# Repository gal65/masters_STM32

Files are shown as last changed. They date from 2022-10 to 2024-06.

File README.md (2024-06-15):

# STM32 board and shield

STM32-based board with shield. Features 12V supply, and voltage converters to power HerkuleX servos as well as the MCU itself. 

Features I2C header (connects to rotary encoder), connection to HerkuleX servo, USB, IMU and temperature sensor, GPIO breakout and CAN bus. Programmable over SWD.

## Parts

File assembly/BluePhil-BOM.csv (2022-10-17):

Designator | Quantity | Value | Footprint | LCSC Part #
C102 C200 C300 C402 C500 | 5 | 10u | Capacitor_SMD:C_0603_1608Metric | C19702
C101 C201 C202 C203 C204 C205 C206 C212 C301 C302 C400 C401 C403 C404 C405 C501 C502 C503 C504 | 19 | 100n | Capacitor_SMD:C_0402_1005Metric | C1525
C100 C207 C208 | 3 | 2u2 | Capacitor_SMD:C_0603_1608Metric | C23630
C209 C210 | 2 | 10p | Capacitor_SMD:C_0402_1005Metric | C32949
C303 | 1 | 10n | Capacitor_SMD:C_0402_1005Metric | C15195
C406 | 1 | 2n2 | Capacitor_SMD:C_0402_1005Metric | C1531
D100 | 1 | LM5Z2V7T1G | Diode_SMD:D_SOD-523 | C131797
D101 | 1 | B5819W | Diode_SMD:D_SOD-123 | C8598
D102 | 1 | GREEN | LED_SMD:LED_0603_1608Metric | C72043
D200 | 1 | BLUE | LED_SMD:LED_0603_1608Metric | C72041
D201 D202 D203 D204 D205 D300 D500 D501 D502 D503 D504 D505 D506 D507 D508 D509 | 16 | RCLAMP0521P-N | Diode_SMD:D_0402_1005Metric | C316043
FB100 FB500 FB501 | 3 | 100R | Inductor_SMD:L_0603_1608Metric | C1002
J200 | 1 | SWD | Connector_PinHeader_1.27mm:PinHeader_2x05_P1.27mm_Vertical | C239059
J201 | 1 | USB_B_Micro | BluePhil-Footprints:MicroXNJ | C404969
J300 | 1 | U.FL | BluePhil-Footprints:BWIPX-1-001E | C496552
J500 | 1 | Micro_SD_Card | BluePhil-Footprints:TF-102-15 | C266609
L1 | 1 | 15u | BluePhil-Footprints:MPIT4018-150M-LF | C281265
L300 | 1 | 100n | Inductor_SMD:L_0402_1005Metric | C22726
Q100 | 1 | AO3401A | Package_TO_SOT_SMD:SOT-23 | C693260
R100 | 1 | 470R | Resistor_SMD:R_0402_1005Metric | C25117
R101 | 1 | 3k4 | Resistor_SMD:R_0402_1005Metric | C4940
R102 | 1 | 1k02 | Resistor_SMD:R_0402_1005Metric | C85373
R200 R202 | 2 | 10k | Resistor_SMD:R_0402_1005Metric | C25744
R201 R301 R302 R500 R501 R502 R503 R504 R505 | 9 | 0R | Resistor_SMD:R_0402_1005Metric | C17168
R203 R204 | 2 | 2k2 | Resistor_SMD:R_0402_1005Metric | C25879
R103 R205 | 2 | 1k | Resistor_SMD:R_0402_1005Metric | C11702
R206 R207 R208 | 3 | 22R | Resistor_SMD:R_0402_1005Metric | C25092
R300 | 1 | 10R | Resistor_SMD:R_0402_1005Metric | C25077
R506 R507 R508 R509 R510 | 5 | 47k | Resistor_SMD:R_0402_1005Metric | C25792
R511 | 1 | 120R | Resistor_SMD:R_0402_1005Metric | C25079
SW200 | 1 | SW_SPDT | Button_Switch_SMD:SW_SPDT_PCM12 | C431541
U100 | 1 | LM2842X | Package_TO_SOT_SMD:TSOT-23-6 | C9403
U200 | 1 | STM32F405RGT6 | Package_QFP:LQFP-64_10x10mm_P0.5mm | C15742
U201 | 1 | USBLC6-2SC6 | Package_TO_SOT_SMD:SOT-23-6 | C7519
U300 | 1 | MAX-M8Q | RF_GPS:ublox_MAX | C90770
U400 | 1 | SPL06-007 | Package_LGA:Bosch_LGA-8_2x2.5mm_P0.65mm_ClockwisePinNumbering | C233787
U401 | 1 | MPU-6050 | Sensor_Motion:InvenSense_QFN-24_4x4mm_P0.5mm | C24112
U500 | 1 | TJA1051T-3 | Package_SO:SOIC-8_3.9x4.9mm_P1.27mm | C38695
Y200 | 1 | 16MHz | Crystal:Crystal_SMD_3225-4Pin_3.2x2.5mm | C13738
 | 1 | BM04B-SURS |  | C495551

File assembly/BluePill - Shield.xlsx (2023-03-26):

Component Count: | 33
Ref | Qnty | Value | Cmp name | Footprint | Vendor | Vendor part number
C202, C209, C502, C503, | 4 | 100n ceramic X5R | C_0402 | SnapEDA Library:CAPC1005X55N | LCSC | C1525
C204, C207, C210, C211, | 4 | 10u ceramic X5R | C_0603 | SnapEDA Library:CAPC1608X90N | LCSC | C19702
D202, D206, | 2 | 30V 2A | D_Schottky | SnapEDA Library:B230A-13-F | Digikey | B230A-FDICT-ND
D501, | 1 | GREEN | LED_Small | LED_SMD:LED_0603_1608Metric | LCSC | C72043
F201, F202, | 2 | 0ZCG0050FF2C | 0ZCG0050FF2C | SnapEDA Library:0ZCG0050FF2C | Digikey | 507-1761-1-ND
IC201, IC202, | 2 | ADP2301AUJZ-R7 | ADP2301AUJZ-R7 | SOT95P280X100-6N | Digikey | 505-ADP2301AUJZ-R7CT-ND
J201, | 1 | AMASS_XT30PW-F | Conn_01x02 | Connector_AMASS:AMASS_XT30PW-F_1x02_P2.50mm_Horizontal | Aliexpress | N/A
J202, | 1 | AMASS_XT30PW-M | Conn_01x02 | Connector_AMASS:AMASS_XT30PW-M_1x02_P2.50mm_Horizontal | Aliexpress | N/A
J501, | 1 | Conn_01x04 | Conn_01x04 | SnapEDA Library:JST_B4B-XH-A(LF)(SN) | Aliexpress | N/A
J502, | 1 | Conn_01x02 | Conn_01x02 | SnapEDA Library:JST_B2B-XH-A(LF)(SN) | Aliexpress | N/A
J504, | 1 | Conn_01x10 | Conn_01x10 | Connector_PinSocket_2.54mm:PinSocket_1x10_P2.54mm_Vertical | Digikey | SAM1198-10-ND
J506, | 1 | Conn_01x13 | Conn_01x13 | Connector_PinSocket_2.54mm:PinSocket_1x13_P2.54mm_Vertical | Digikey | SAM1198-13-ND
L201, L203, | 2 | 4.7u 2.0A | L | SnapEDA Library:CDRH5D28RHPNP-4R7NC | Digikey | 308-2068-1-ND
R201, R205, R212, | 3 | 56k | R_Small | Resistor_SMD:R_0402_1005Metric | Digikey | 311-56.0KLRCT-ND
R202, | 1 | 6.8k | R_Small | Resistor_SMD:R_0402_1005Metric | Digikey | 311-6.80KLRCT-ND
R206, R213, | 2 | 10.2k | R_Small | Resistor_SMD:R_0402_1005Metric | Digikey | YAG2950CT-ND
R210, | 1 | 52.3k | R_Small | Resistor_SMD:R_0402_1005Metric | Digikey | YAG3179CT-ND
R211, | 1 | 10k | R_Small | Resistor_SMD:R_0402_1005Metric | LCSC | C25744
R501, | 1 | 1k | R_Small | Resistor_SMD:R_0402_1005Metric | LCSC | C11702
U502, | 1 | TXS0102DCU | TXS0102DCU | Package_SO:VSSOP-8_2.3x2mm_P0.5mm | Digikey | 296-21931-1-ND

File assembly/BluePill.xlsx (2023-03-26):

Component Count: | 66
Ref | Qnty | Value | Cmp name | Footprint | Vendor | Vendor part number
C201, C205, | 2 | 1u ceramic X7R | C0603C105K3RACTU | SnapEDA Library:C0603C105K3RACTU | Digikey | 399-C0603C105K3RAC7867CT-ND
C301, C302, | 2 | 10p | C_Small | Capacitor_SMD:C_0402_1005Metric | LCSC | C32949
C303, | 1 | 10u | C_Small | Capacitor_SMD:C_0603_1608Metric | Digikey | 1276-1119-1-ND
C304, C306, | 2 | 2u2 | C_Small | Capacitor_SMD:C_0603_1608Metric | LCSC | C23630
C305, C307, C308, C309, C310, C311, C312, C402 C501, | 9 | 100n X7R | C_Small | Capacitor_SMD:C_0402_1005Metric | LCSC | C1525
C401, | 1 | 10n | C_Small | Capacitor_SMD:C_0402_1005Metric | LCSC | C15195
C403, | 1 | 2u2 X7R | C_Small | Capacitor_SMD:C_0402_1005Metric | Digikey | 490-GRM155Z71A225KE44DCT-ND
D204, | 1 | GREEN | LED_Small | LED_SMD:LED_0603_1608Metric | LCSC | C72043
D301, | 1 | BLUE | LED_Small | LED_SMD:LED_0603_1608Metric | LCSC | C72041
D302, D303, D304, D305, D306, D502, D503, | 7 | RCLAMP0521P-N | D_TVS | Diode_SMD:D_0402_1005Metric | LCSC | C316043
D307, | 1 | YELLOW | LED_Small | LED_SMD:LED_0603_1608Metric | Digikey | 160-1831-1-ND
D308, | 1 | RED | LED_Small | LED_SMD:LED_0603_1608Metric | Digikey | 160-1830-1-ND
H501, H502, | 2 | MountingHole_Pad | MountingHole_Pad | MountingHole:MountingHole_3.2mm_M3_Pad_Via | N/A | N/A
J301, | 1 | SWD | Conn_02x05_Odd_Even | Connector_PinHeader_1.27mm:PinHeader_2x05_P1.27mm_Vertical | LCSC | C239059
J302, | 1 | USB4110-GF-A_REVB | USB4110-GF-A_REVB | SnapEDA Library:GCT_USB4110-GF-A_REVB | Digikey | 2073-USB4110-GF-A-1-ND
J401, | 1 | BM04B-SURS-TFLFSN | BM04B-SURS-TFLFSN | SnapEDA Library:JST_BM04B-SURS-TF(LF)(SN) | LCSC | C495551
J503, | 1 | Conn_01x10 | Conn_01x10 | Connector_PinSocket_2.54mm:PinSocket_1x10_P2.54mm_Vertical | Digikey | S7043-ND
J505, | 1 | Conn_01x13 | Conn_01x13 | Connector_PinSocket_2.54mm:PinSocket_1x13_P2.54mm_Vertical | Digikey | S7046-ND
JP401, JP402, | 2 | SolderJumper_3_Bridged12 | SolderJumper_3_Bridged12 | Jumper:SolderJumper-3_P1.3mm_Bridged12_Pad1.0x1.5mm | N/A | N/A
R208, R306, R313, R317, | 4 | 1k | R_Small | Resistor_SMD:R_0402_1005Metric | LCSC | C11702
R301, R307, R309, R310, R311, R312, | 6 | 2k2 | R_Small | Resistor_SMD:R_0402_1005Metric | LCSC | C25879
R302, R401, R402, | 3 | 0R | R_Small | Resistor_SMD:R_0402_1005Metric | LCSC | C17168
R303, R308, | 2 | 10k | R_Small | Resistor_SMD:R_0402_1005Metric | LCSC | C25744
R304, R305, | 2 | 5k1 | R_Small | Resistor_SMD:R_0402_1005Metric | Digikey | 311-5.10KLRCT-ND
R314, R315, R316, | 3 | 22R | R_Small | Resistor_SMD:R_0402_1005Metric | LCSC | C25092
R502, | 1 | 120R | R_Small | Resistor_SMD:R_0402_1005Metric | LCSC | C25079
SW301, | 1 | SW_SPDT | SW_SPDT | Button_Switch_SMD:SW_SPDT_PCM12 | Digikey | 401-2016-1-ND
U201, | 1 | LP5907QMFX-3.3Q1 | LP5907QMFX-3.3Q1 | SnapEDA Library:SOT95P280X145-5N | Digikey | 296-40365-1-ND
U301, | 1 | STM32F405RGT6 | STM32F405RGTx | Package_QFP:LQFP-64_10x10mm_P0.5mm | LCSC | C15742
U302, | 1 | USBLC6-2SC6 | USBLC6-2SC6 | Package_TO_SOT_SMD:SOT-23-6 | LCSC | C7519
U401, | 1 | ICM-42670-P | ICM-42670-P | SnapEDA Library:IC_ICM-42670-P | Digikey | 1428-ICM-42670-PCT-ND
U501, | 1 | SN65HVD232QDRQ1 | SN65HVD232QDRQ1 | SnapEDA Library:SOIC127P599X175-8N | Digikey | 296-15381-1-ND
Y301, | 1 | 16MHz | Crystal_GND24_Small | Crystal:Crystal_SMD_3225-4Pin_3.2x2.5mm | LCSC | C13738

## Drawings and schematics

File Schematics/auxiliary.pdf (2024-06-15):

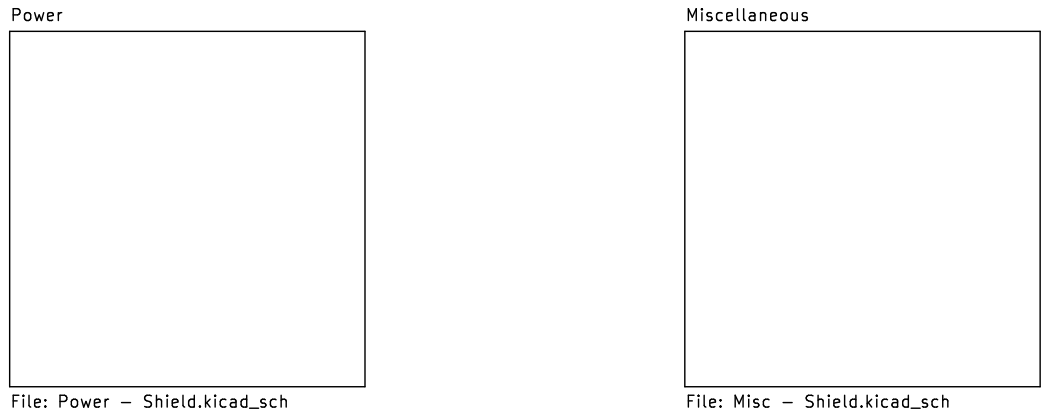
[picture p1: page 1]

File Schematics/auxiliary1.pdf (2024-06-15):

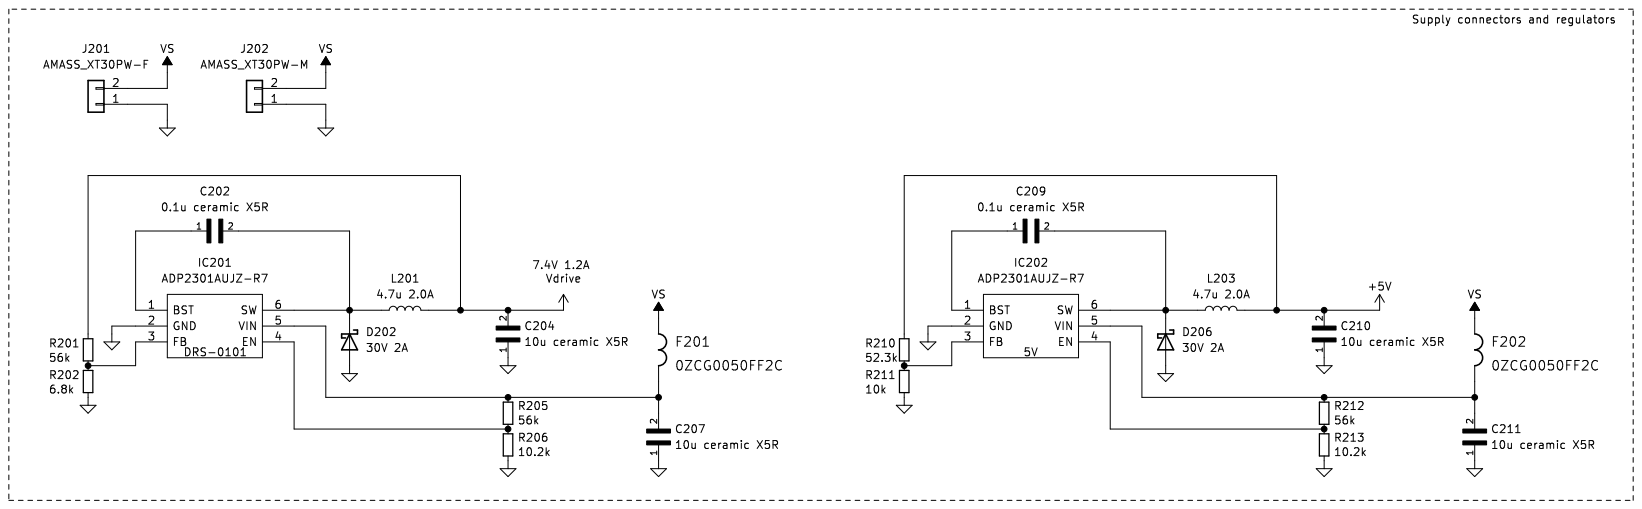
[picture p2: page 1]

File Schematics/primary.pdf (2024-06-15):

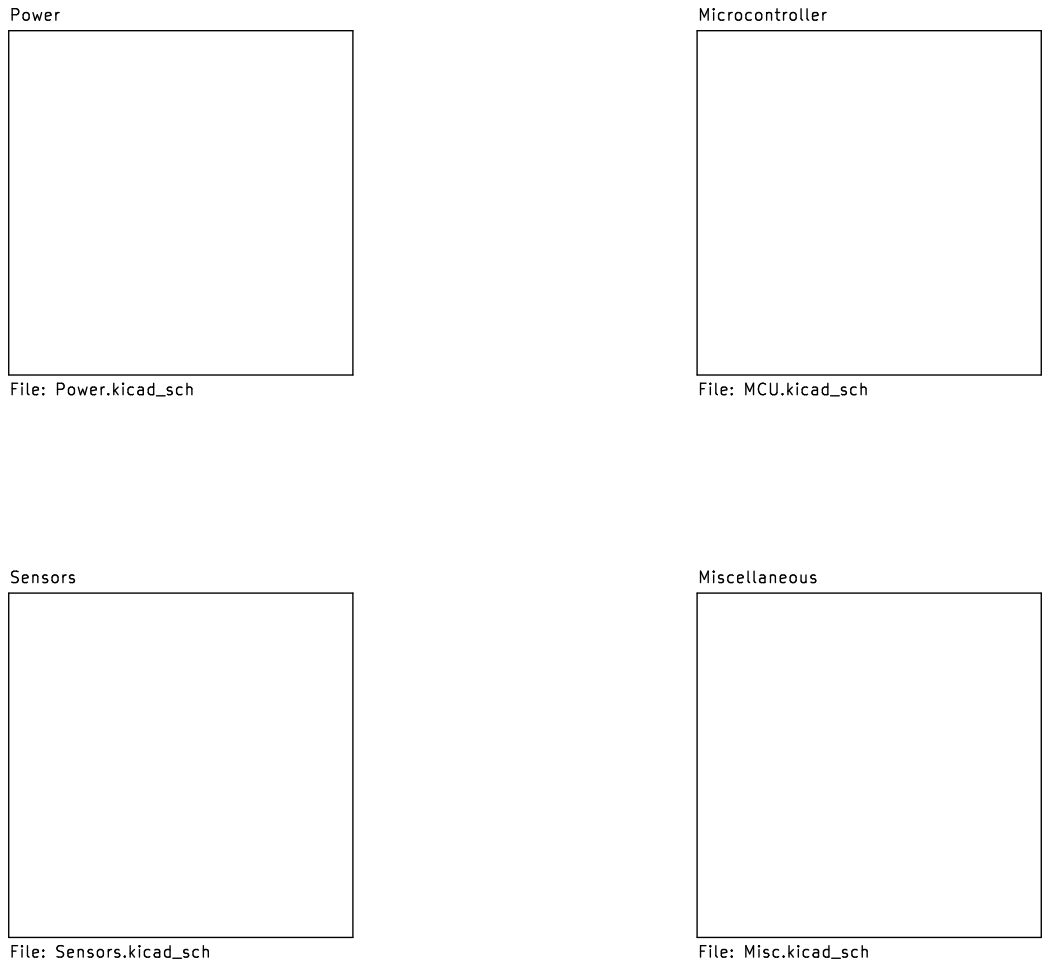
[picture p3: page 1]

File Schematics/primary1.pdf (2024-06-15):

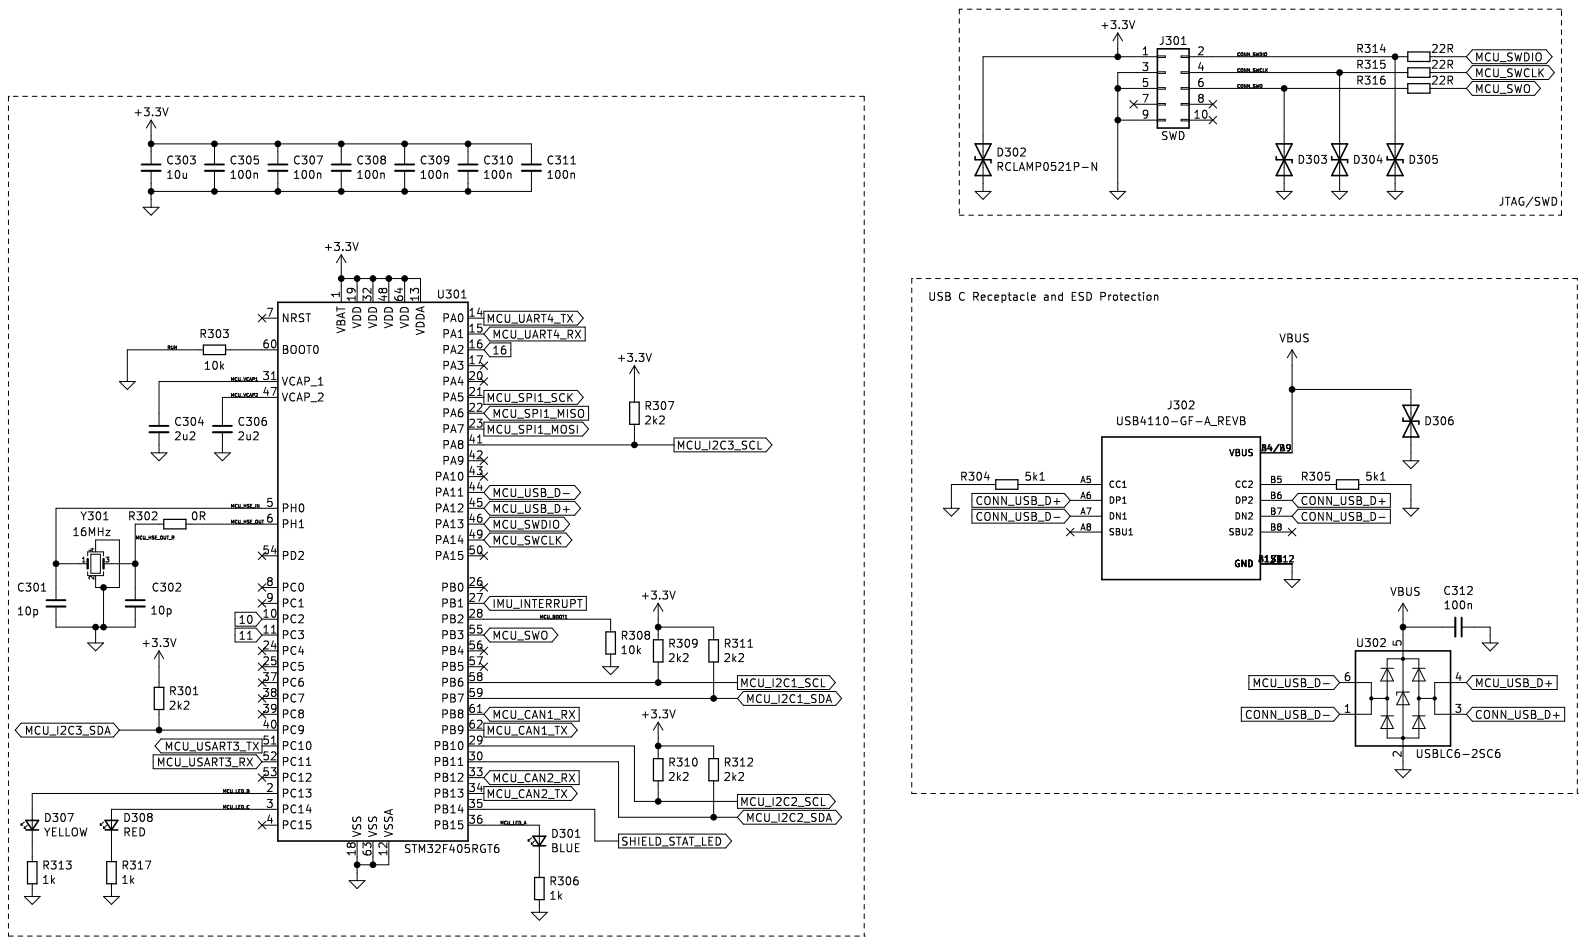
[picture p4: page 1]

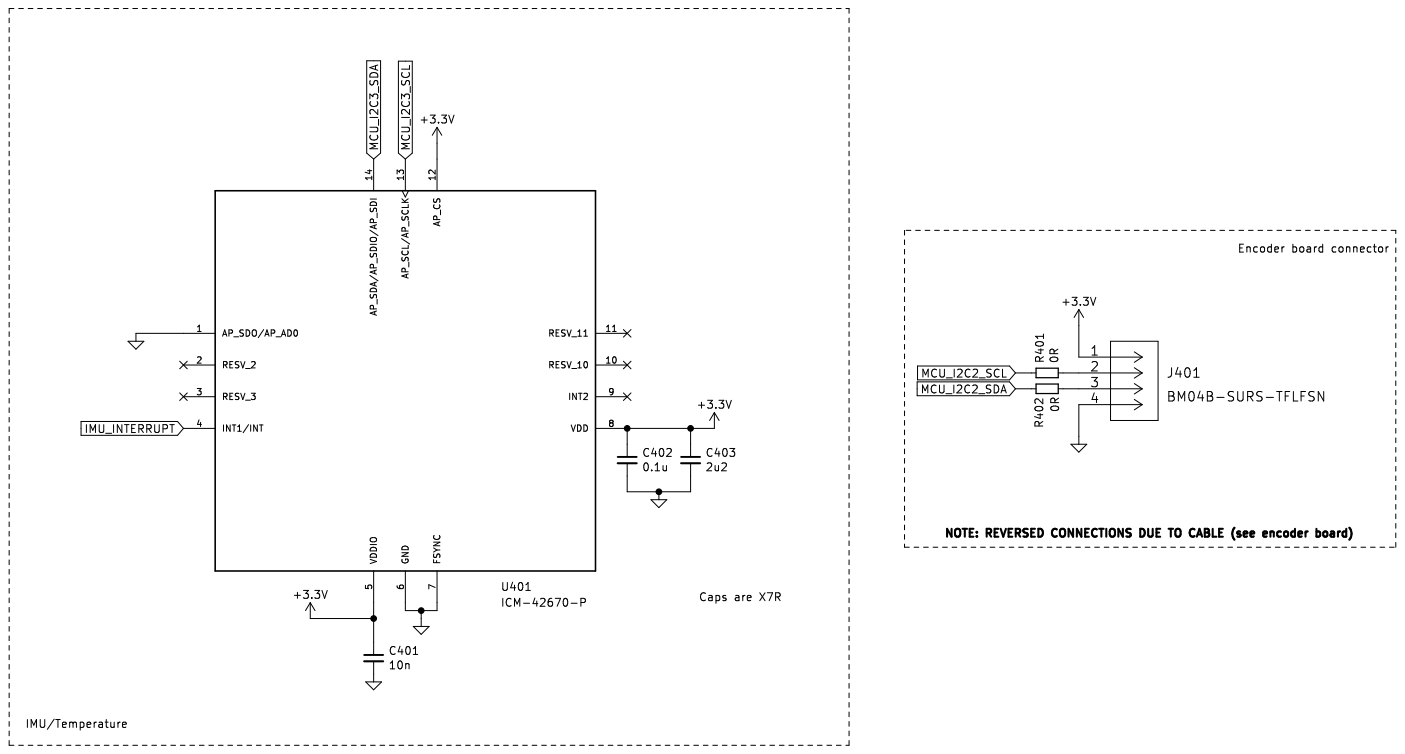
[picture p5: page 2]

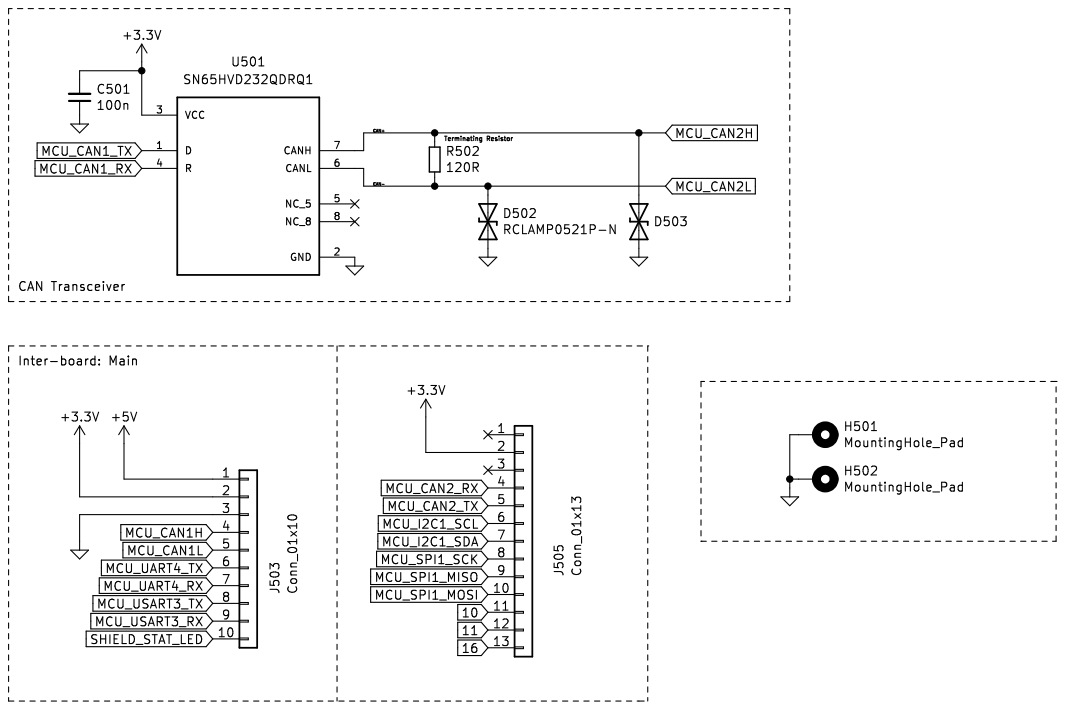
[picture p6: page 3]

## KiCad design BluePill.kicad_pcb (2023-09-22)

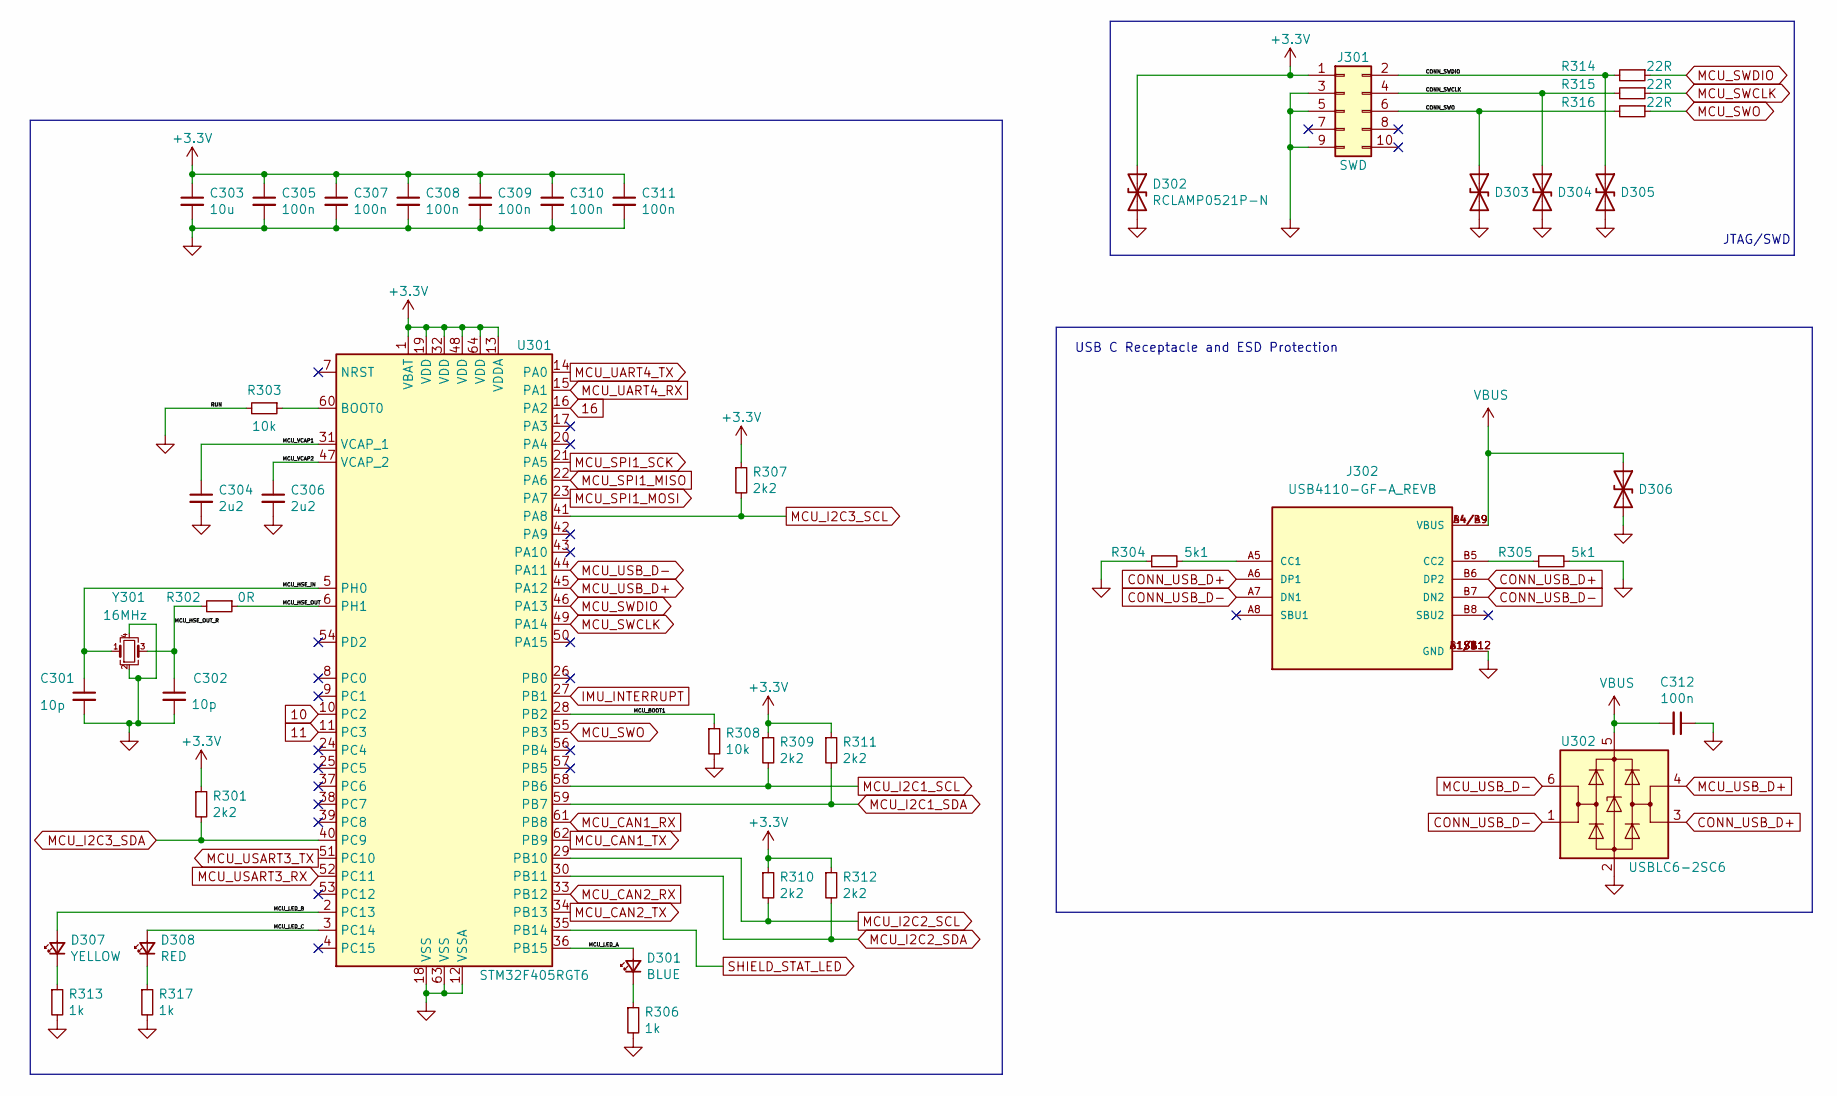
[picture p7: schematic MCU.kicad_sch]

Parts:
C301, C302: 10p; C_0402_1005Metric; LCSC Part # C32949
C303: 10u; C_0603_1608Metric; LCSC Part # C19702
C304, C306: 2u2; C_0603_1608Metric; LCSC Part # C23630
C305, C307, C308, C309, C310, C311, C312: 100n; C_0402_1005Metric; LCSC Part # C1525
D301: BLUE; LED_0603_1608Metric; LCSC Part # C72041
D302, D303, D304, D305, D306: RCLAMP0521P-N; D_0402_1005Metric; LCSC Part # C316043
D307: YELLOW; LED_0603_1608Metric; LCSC Part # C72041
D308: RED; LED_0603_1608Metric; LCSC Part # C72041
J301: SWD; PinHeader_2x05_P1.27mm_Vertical; LCSC Part # C239059
J302: USB4110-GF-A_REVB; GCT_USB4110-GF-A_REVB; PARTREV B
R301, R307, R309, R310, R311, R312: 2k2; R_0402_1005Metric; LCSC Part # C25879
R302: 0R; R_0402_1005Metric; LCSC Part # C17168
R303, R308: 10k; R_0402_1005Metric; LCSC Part # C25744
R304, R305: 5k1; R_0402_1005Metric; LCSC Part # C25879
R306, R313, R317: 1k; R_0402_1005Metric; LCSC Part # C11702
R314, R315, R316: 22R; R_0402_1005Metric; LCSC Part # C25092
U301: STM32F405RGT6; LQFP-64_10x10mm_P0.5mm; LCSC Part # C15742
U302: USBLC6-2SC6; SOT-23-6; LCSC Part # C7519
Y301: 16MHz; Crystal_SMD_3225-4Pin_3.2x2.5mm; LCSC Part # C13738

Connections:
10: U301.10 (PC2); also elsewhere on the board
11: U301.11 (PC3); also elsewhere on the board
16: U301.16 (PA2); also elsewhere on the board
+3V3: C303.1, C305.1, C307.1, C308.1, C309.1, C310.1, C311.1, D302.1 (A1), J301.1, R301.1, R307.1, R309.1, R310.1, R311.1, R312.1, U301.1 (VBAT), U301.13 (VDDA), U301.19 (VDD), U301.32 (VDD), U301.48 (VDD), U301.64 (VDD); also elsewhere on the board
/Microcontroller/CONN_SWCLK: D304.1 (A1), J301.4, R315.2
/Microcontroller/CONN_SWDIO: D305.1 (A1), J301.2, R314.2
/Microcontroller/CONN_SWO: D303.1 (A1), J301.6, R316.2
/Microcontroller/MCU_BOOT1: R308.1, U301.28 (PB2)
/Microcontroller/MCU_HSE_IN: C301.1, U301.5 (PH0), Y301.1
/Microcontroller/MCU_HSE_OUT: R302.1, U301.6 (PH1)
/Microcontroller/MCU_HSE_OUT_R: C302.1, R302.2, Y301.3
/Microcontroller/MCU_LED_A: D301.2 (A), U301.36 (PB15)
/Microcontroller/MCU_LED_B: D307.2 (A), U301.2 (PC13)
/Microcontroller/MCU_LED_C: D308.2 (A), U301.3 (PC14)
/Microcontroller/MCU_VCAP1: C304.1, U301.31 (VCAP_1)
/Microcontroller/MCU_VCAP2: C306.1, U301.47 (VCAP_2)
CONN_USB_D+: J302.A6 (DP1), J302.B6 (DP2), U302.3 (I/O2)
CONN_USB_D-: J302.A7 (DN1), J302.B7 (DN2), U302.1 (I/O1)
GND: C301.2, C302.2, C303.2, C304.2, C305.2, C306.2, C307.2, C308.2, C309.2, C310.2, C311.2, C312.1, D302.2 (A2), D303.2 (A2), D304.2 (A2), D305.2 (A2), D306.2 (A2), J301.3, J301.5, J301.9, J302.A1/B12 (GND), J302.B1/A12 (GND), J302.S1 (GND), J302.S2 (GND), J302.S3 (GND), J302.S4 (GND), R303.2, R304.1, R305.2, R306.2, R308.2, R313.2, R317.2, U301.12 (VSSA), U301.18 (VSS), U301.63 (VSS), U302.2 (GND), Y301.2, Y301.4; also elsewhere on the board
IMU_INTERRUPT: U301.27 (PB1); also elsewhere on the board
MCU_CAN1_RX: U301.61 (PB8); also elsewhere on the board
MCU_CAN1_TX: U301.62 (PB9); also elsewhere on the board
MCU_CAN2_RX: U301.33 (PB12); also elsewhere on the board
MCU_CAN2_TX: U301.34 (PB13); also elsewhere on the board
MCU_I2C1_SCL: R309.2, U301.58 (PB6); also elsewhere on the board
MCU_I2C1_SDA: R311.2, U301.59 (PB7); also elsewhere on the board
MCU_I2C3_SCL: R307.2, U301.41 (PA8); also elsewhere on the board
MCU_I2C3_SDA: R301.2, U301.40 (PC9); also elsewhere on the board
MCU_SPI1_MISO: U301.22 (PA6); also elsewhere on the board
MCU_SPI1_MOSI: U301.23 (PA7); also elsewhere on the board
MCU_SPI1_SCK: U301.21 (PA5); also elsewhere on the board
MCU_SWCLK: R315.1, U301.49 (PA14)
MCU_SWDIO: R314.1, U301.46 (PA13)
MCU_SWO: R316.1, U301.55 (PB3)
MCU_UART4_RX: U301.15 (PA1); also elsewhere on the board
MCU_UART4_TX: U301.14 (PA0); also elsewhere on the board
MCU_USART3_RX: U301.52 (PC11); also elsewhere on the board
MCU_USART3_TX: U301.51 (PC10); also elsewhere on the board
MCU_USB_D+: U301.45 (PA12), U302.4 (I/O2)
MCU_USB_D-: U301.44 (PA11), U302.6 (I/O1)
unnamed: D301.1 (K), R306.1
unnamed: D307.1 (K), R313.1
unnamed: D308.1 (K), R317.1
unnamed: J302.A5 (CC1), R304.2
unnamed: J302.B5 (CC2), R305.1
unnamed: R303.1, U301.60 (BOOT0)
SHIELD_STAT_LED: U301.35 (PB14); also elsewhere on the board
VBUS: C312.2, D306.1 (A1), J302.A4/B9 (VBUS), J302.B4/A9 (VBUS), U302.5 (VBUS)

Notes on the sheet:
USB C Receptacle and ESD Protection
JTAG/SWD

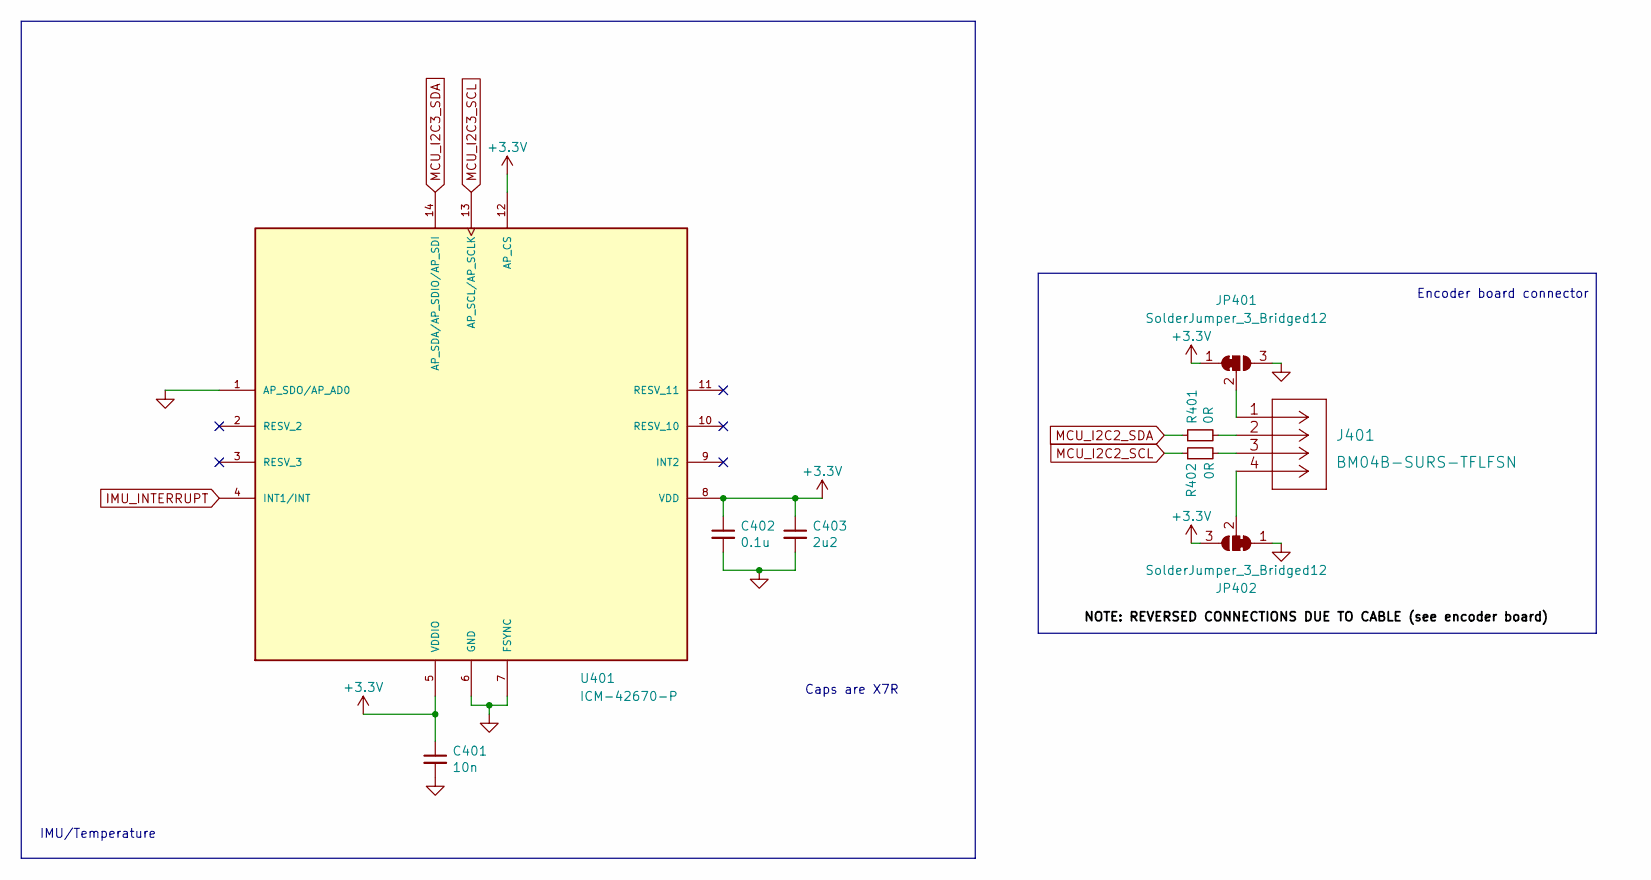
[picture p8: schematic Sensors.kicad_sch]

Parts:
C401: 10n; C_0402_1005Metric; LCSC Part # C1531
C402: 0.1u; C_0402_1005Metric; LCSC Part # C1525
C403: 2u2; C_0402_1005Metric; LCSC Part # C1531
J401: BM04B-SURS-TFLFSN; JST_BM04B-SURS-TF(LF)(SN)
JP401, JP402: SolderJumper_3_Bridged12; SolderJumper-3_P1.3mm_Bridged12_Pad1.0x1.5mm
R401, R402: 0R; R_0402_1005Metric; LCSC Part # C25079
U401: ICM-42670-P; IC_ICM-42670-P; PARTREV 1.0

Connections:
+3V3: C401.1, C402.1, C403.1, J401.1, JP401.1 (A), JP401.2 (C), JP402.3 (B), U401.5 (VDDIO), U401.8 (VDD), U401.12 (AP_CS); also elsewhere on the board
GND: C401.2, C402.2, C403.2, J401.4, JP401.3 (B), JP402.1 (A), JP402.2 (C), U401.1 (AP_SDO/AP_AD0), U401.6 (GND), U401.7 (FSYNC); also elsewhere on the board
IMU_INTERRUPT: U401.4 (INT1/INT); also elsewhere on the board
MCU_I2C3_SCL: U401.13 (AP_SCL/AP_SCLK); also elsewhere on the board
MCU_I2C3_SDA: U401.14 (AP_SDA/AP_SDIO/AP_SDI); also elsewhere on the board
unnamed: J401.2, R401.2
unnamed: J401.3, R402.2

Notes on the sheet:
Encoder board connector
Caps are X7R
IMU/Temperature

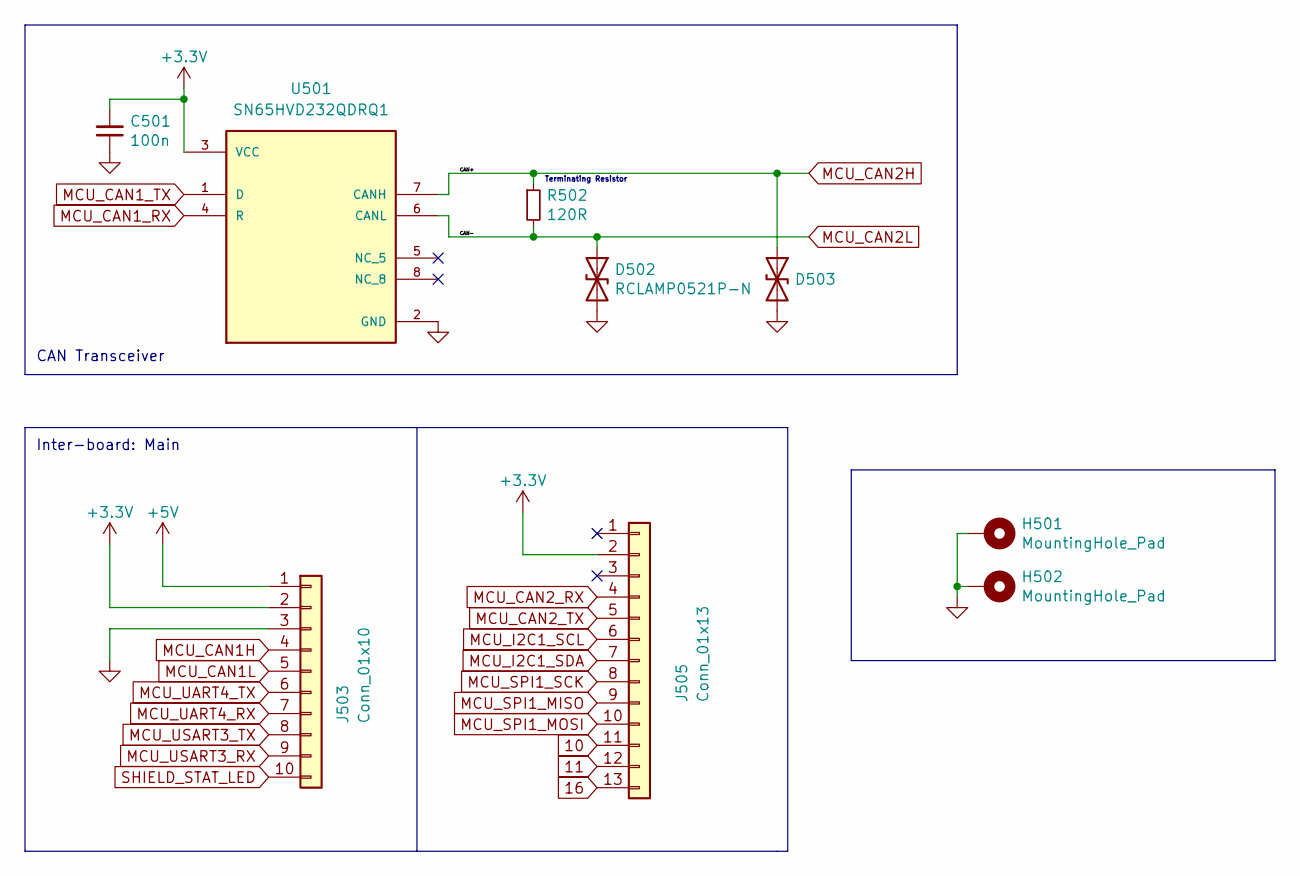
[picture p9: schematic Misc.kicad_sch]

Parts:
C501: 100n; C_0402_1005Metric; LCSC Part # C1525
D502, D503: RCLAMP0521P-N; D_0402_1005Metric; LCSC Part # C316043
H501, H502: MountingHole_Pad; MountingHole_3.2mm_M3_Pad_Via
J503: Conn_01x10; PinSocket_1x10_P2.54mm_Vertical
J505: Conn_01x13; PinSocket_1x13_P2.54mm_Vertical
R502: 120R; R_0402_1005Metric; LCSC Part # C25079
U501: SN65HVD232QDRQ1; SOIC127P599X175-8N; PARTREV APRIL 2008

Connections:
10: J505.11; also elsewhere on the board
11: J505.12; also elsewhere on the board
16: J505.13; also elsewhere on the board
+3V3: C501.2, J503.2, J505.2, U501.3 (VCC); also elsewhere on the board
+5V: J503.1; also elsewhere on the board
GND: C501.1, D502.2 (A2), D503.2 (A2), H501.1, H502.1, J503.3, U501.2 (GND); also elsewhere on the board
MCU_CAN1H: J503.4
MCU_CAN1L: J503.5
MCU_CAN1_RX: U501.4 (R); also elsewhere on the board
MCU_CAN1_TX: U501.1 (D); also elsewhere on the board
MCU_CAN2H: D503.1 (A1), R502.1, U501.7 (CANH)
MCU_CAN2L: D502.1 (A1), R502.2, U501.6 (CANL)
MCU_CAN2_RX: J505.4; also elsewhere on the board
MCU_CAN2_TX: J505.5; also elsewhere on the board
MCU_I2C1_SCL: J505.6; also elsewhere on the board
MCU_I2C1_SDA: J505.7; also elsewhere on the board
MCU_SPI1_MISO: J505.9; also elsewhere on the board
MCU_SPI1_MOSI: J505.10; also elsewhere on the board
MCU_SPI1_SCK: J505.8; also elsewhere on the board
MCU_UART4_RX: J503.7; also elsewhere on the board
MCU_UART4_TX: J503.6; also elsewhere on the board
MCU_USART3_RX: J503.9; also elsewhere on the board
MCU_USART3_TX: J503.8; also elsewhere on the board
SHIELD_STAT_LED: J503.10; also elsewhere on the board

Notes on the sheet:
CAN Transceiver
Terminating Resistor
Inter-board: Main

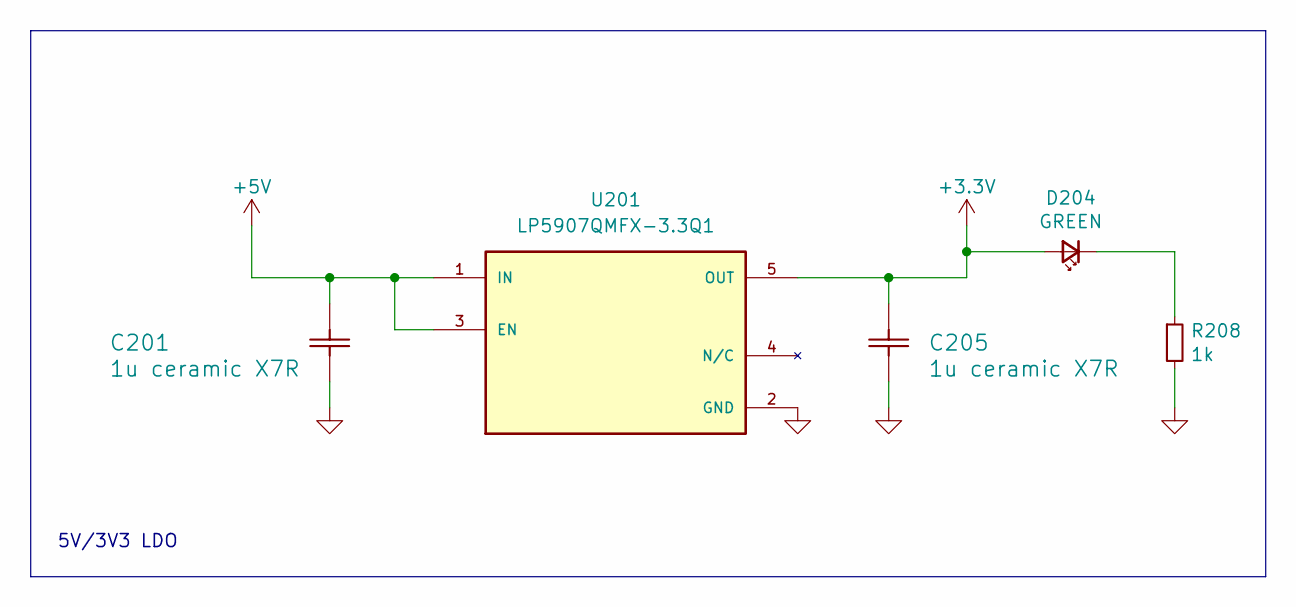
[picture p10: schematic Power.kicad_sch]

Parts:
C201, C205: 1u ceramic X7R; C0603C105K3RACTU
D204: GREEN; LED_0603_1608Metric; LCSC Part # C72043
R208: 1k; R_0402_1005Metric; LCSC Part # C11702
U201: LP5907QMFX-3.3Q1; SOT95P280X145-5N; PARTREV DECEMBER 2019

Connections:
+3V3: C205.2, D204.2 (A), U201.5 (OUT); also elsewhere on the board
+5V: C201.2, U201.1 (IN), U201.3 (EN); also elsewhere on the board
GND: C201.1, C205.1, R208.2, U201.2 (GND); also elsewhere on the board
unnamed: D204.1 (K), R208.1

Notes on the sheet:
5V/3V3 LDO

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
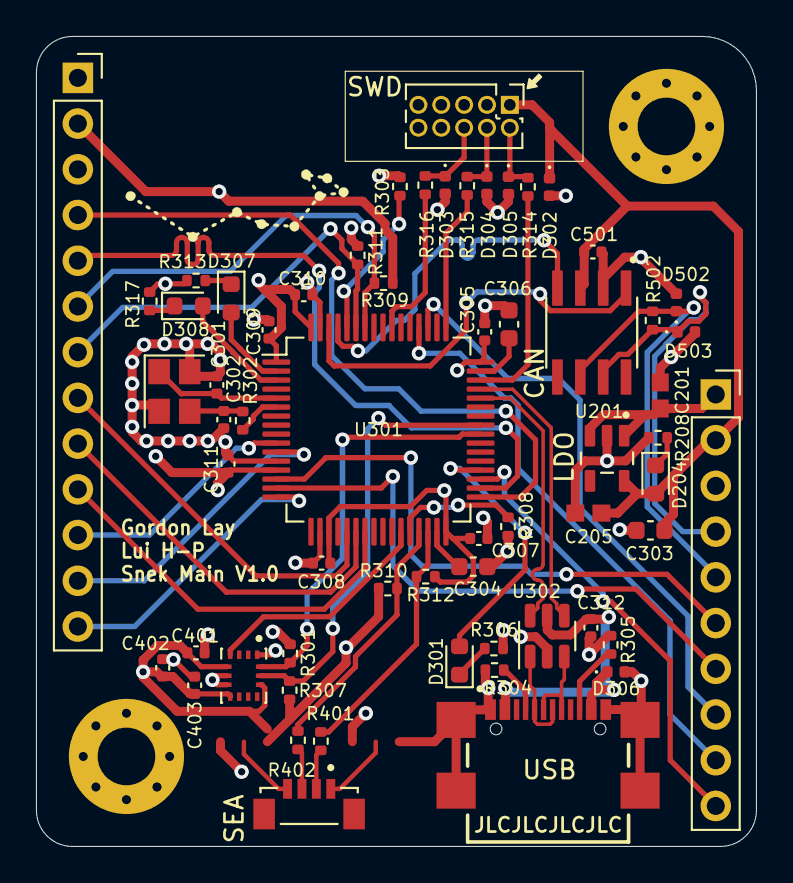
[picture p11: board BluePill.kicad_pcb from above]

Board: 4 copper layers, 40.0 x 45.0 mm, 63 parts (0 on the bottom side), 56 nets.

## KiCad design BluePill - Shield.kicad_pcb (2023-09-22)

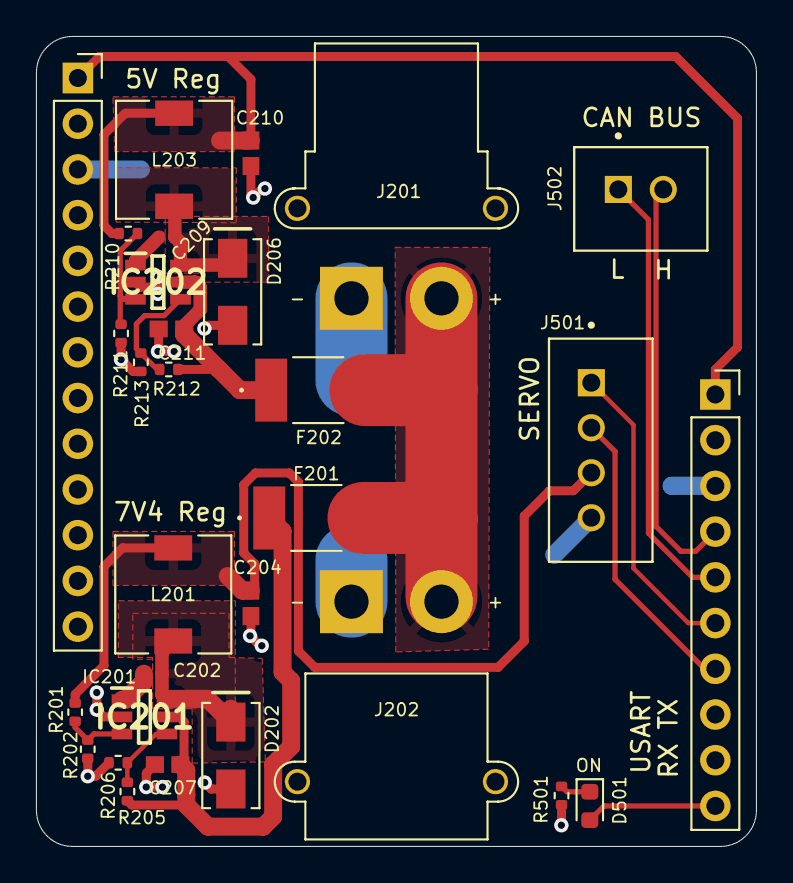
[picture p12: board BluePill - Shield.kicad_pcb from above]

Board: 2 copper layers, 40.0 x 45.0 mm, 30 parts (0 on the bottom side), 20 nets.

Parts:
C202, C209: 0.1u ceramic X5R; CAPC1005X55N
C204, C207, C210, C211: 10u ceramic X5R; CAPC1608X90N
D202, D206: 30V 2A; B230A-13-F
D501: GREEN; LED_0603_1608Metric
F201, F202: 0ZCG0050FF2C
IC201, IC202: ADP2301AUJZ-R7; SOT95P280X100-6N
J201: AMASS_XT30PW-F; AMASS_XT30PW-F_1x02_P2.50mm_Horizontal
J202: AMASS_XT30PW-M; AMASS_XT30PW-M_1x02_P2.50mm_Horizontal
J501: Conn_01x04; JST_B4B-XH-A(LF)(SN)
J502: Conn_01x02; JST_B2B-XH-A(LF)(SN)
J504: Conn_01x10; PinSocket_1x10_P2.54mm_Vertical
J506: Conn_01x13; PinSocket_1x13_P2.54mm_Vertical
L201, L203: 4.7u 2.0A; CDRH5D28RHPNP-4R7NC
R201, R205, R212: 56k; R_0402_1005Metric
R202: 6.8k; R_0402_1005Metric
R206, R213: 10.2k; R_0402_1005Metric
R210: 52.3k; R_0402_1005Metric
R211: 10k; R_0402_1005Metric
R501: 1k; R_0402_1005Metric

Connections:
+5V: C210.2, J504.1, J506.1, L203.2, R210.1
GND: C204.1, C207.1, C210.1, C211.1, D202.2 (A), D206.2 (A), IC201.2 (GND), IC202.2 (GND), J201.1, J202.1, J501.4, J504.3, J506.3, R202.2, R206.2, R211.2, R213.2, R501.2
unnamed: C202.1, IC201.1 (BST)
unnamed: C202.2, D202.1 (K), IC201.6 (SW), L201.1
unnamed: C207.2, F201.1, IC201.5 (VIN), R205.1
unnamed: C209.1, IC202.1 (BST)
unnamed: C209.2, D206.1 (K), IC202.6 (SW), L203.1
unnamed: C211.2, F202.1, IC202.5 (VIN), R212.1
unnamed: D501.1 (K), R501.1
unnamed: D501.2 (A), J504.10
unnamed: IC201.3 (FB), R201.2, R202.1
unnamed: IC201.4 (EN), R205.2, R206.1
unnamed: IC202.3 (FB), R210.2, R211.1
unnamed: IC202.4 (EN), R212.2, R213.1
SHIELD_CAN1H: J502.2, J504.4
SHIELD_CAN1L: J502.1, J504.5
UART4_RX/SERVO_TX: J501.2, J504.7
UART4_TX/SERVO_RX: J501.1, J504.6
VS: F201.2, F202.2, J201.2, J202.2
Vdrive: C204.2, J501.3, L201.2, R201.1

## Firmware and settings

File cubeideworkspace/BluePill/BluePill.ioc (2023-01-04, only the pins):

Mcu.UserName=STM32F405RGTx
PA0-WKUP.GPIO_Label=SERVO_TX
PA0-WKUP.Signal=UART4_TX
PA1.GPIO_Label=SERVO_RX
PA1.Signal=UART4_RX
PA10.GPIO_Label=NC?
PA10.Signal=USB_OTG_FS_ID
PA11.Signal=USB_OTG_FS_DM
PA12.Signal=USB_OTG_FS_DP
PA13.Signal=SYS_JTMS-SWDIO
PA14.Signal=SYS_JTCK-SWCLK
PA2.Signal=GPIO_Analog
PA5.Signal=SPI1_SCK
PA6.Signal=SPI1_MISO
PA7.Signal=SPI1_MOSI
PA8.GPIO_Label=I2C3_SCL (IMU)
PA8.Signal=I2C3_SCL
PB1.GPIO_Label=IMU_INTERRUPT
PB1.Signal=GPXTI1
PB10.GPIO_Label=I2C2_SCL (encoder)
PB10.Signal=I2C2_SCL
PB11.GPIO_Label=I2C_SDA (encoder)
PB11.Signal=I2C2_SDA
PB12.GPIO_Label=CAN2_RX (CAN bus)
PB12.Signal=CAN2_RX
PB13.GPIO_Label=CAN2_TX (CAN bus)
PB13.Signal=CAN2_TX
PB14.GPIO_Label=SHIELD_STAT_LED
PB14.Signal=GPIO_Analog
PB15.GPIO_Label=MCU_LED_A
PB15.Signal=GPIO_Output
PB2.GPIO_Label=MCU_BOOT1
PB2.Signal=GPIO_Analog
PB3.Signal=SYS_JTDO-SWO
PB6.GPIO_Label=MCU_I2C1_SCL
PB6.Signal=I2C1_SCL
PB7.GPIO_Label=MCU_I2C1_SDA
PB7.Signal=I2C1_SDA
PB8.GPIO_Label=MCU_CAN1_RX
PB8.Signal=CAN1_RX
PB9.GPIO_Label=MCU_CAN1_TX
PB9.Signal=CAN1_TX
PC10.GPIO_Label=MCU_USART3_TX
PC10.Signal=USART3_TX
PC11.GPIO_Label=MCU_USART3_RX
PC11.Signal=USART3_RX
PC2.Signal=GPIO_Analog
PC3.Signal=GPIO_Analog
PC9.GPIO_Label=I2C3_SDA (IMU)
PC9.Signal=I2C3_SDA
PH0-OSC_IN.GPIO_Label=MCU_HSE_IN
PH0-OSC_IN.Signal=RCC_OSC_IN
PH1-OSC_OUT.GPIO_Label=MCU_HSE_OUT
PH1-OSC_OUT.Signal=RCC_OSC_OUT

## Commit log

2022-10-11 small refactor
    [BluePhil-B_Cu.gbr, BluePhil-B_Mask.gbr, BluePhil-Edge_Cuts.gbr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]
2022-10-13 replaced CAN transceiver, introduced new IMU
    [BluePill.kicad_pcb, BluePill.kicad_sch, MCU.kicad_sch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]
2022-10-14 some more changes
    [BluePill.kicad_pcb]
2022-10-17 BOM stuff
    [BOM1.xlsx, BluePhil-BOM.csv, LCSC_Exported_20221017_183607.csv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]
2022-10-18 added cubeide workspace
    [BluePill.kicad_sch, MCU.kicad_sch, Misc.kicad_sch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]
2022-10-19 more changes
    [BluePill.kicad_sch, Misc.kicad_sch]
2022-10-20 more changes!
    [BluePill.kicad_pcb, BluePill.kicad_sch, MCU.kicad_sch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]
2022-10-24 more progress
    [BluePill.kicad_pcb, BluePill.kicad_sch, Misc.kicad_sch]
2022-10-25 this is a message
    [BluePill.kicad_pcb, MCU.kicad_sch, Misc.kicad_sch]
2022-10-26 gpio breakout stuff
    [BluePill.kicad_pcb, BluePill.kicad_sch, MCU.kicad_sch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]
2022-11-07 final commit before holiday
    [BluePill.kicad_pcb, BluePill.kicad_sch, MCU.kicad_sch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]
2022-12-06 back from KL
    [BluePill.kicad_pcb, BluePill.kicad_sch, Misc.kicad_sch]
2023-01-25 First draft routing
    Separated into shield and main board projects
    [BluePill - Shield.kicad_pcb, BluePill - Shield.kicad_sch, BluePill.kicad_pcb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]
2023-01-26 DRC fix ups
    [BluePill - Shield.kicad_pcb, BluePill.kicad_pcb]
2023-02-13 reworked main board for 4 layers
    [BluePill - Shield.kicad_pcb, BluePill.kicad_pcb, BluePill.kicad_sch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]
2023-09-22 incorporated rework into official design
    [BluePill - Shield.kicad_pcb, BluePill - Shield.kicad_sch, BluePill.kicad_pcb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]

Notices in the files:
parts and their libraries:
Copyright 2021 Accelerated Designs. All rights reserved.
